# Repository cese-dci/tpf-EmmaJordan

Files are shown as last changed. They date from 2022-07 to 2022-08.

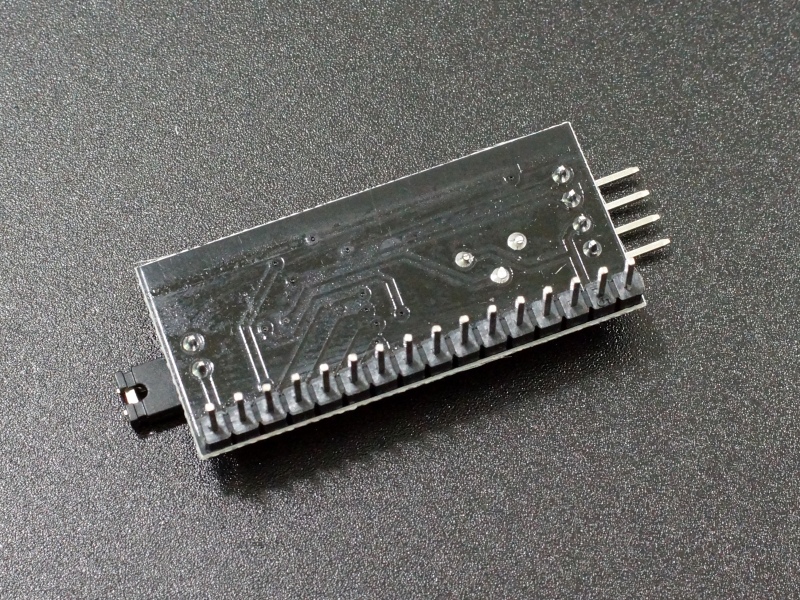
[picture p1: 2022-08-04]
doc/LCDi2c Vista Inferior.jpg

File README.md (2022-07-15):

## Trabajo práctico final de la asignatura DCI ##
Este repositorio contiene el trabajo práctico final para la asignatura de Diseño de Circuitos Impresos de la carrera de posgrado de FIUBA.

* Autor: Jordán Joan Emmanuel
* Título corto del trabajo:  Adaptador LCD i2c para Displays Alfanuméricos
* Resumen:  Este trabajo consiste en el diseño de una placa electrónica para control de Displays Alfanuméricos desde microcontrolador.
Mediante interfaz LCD-i2c. La placa utiliza como integrado principal el PCF8574, el cual traduce la comunicación i2c con el microcontrolador
a puerto paralelo para el Display, el cual puede ser 16x02, 20x4, 40x2, etc.

* Descripción: El módulo LCD-i2c es un expansor de puertos I2C, para controlar desde un microcontrolador con sólo dos pines (SCL y SDA), 
un display alfanumérico tipo 16x2, 20x4, 40x2, etc. Cuenta con un potenciómetro para ajustar el contraste de la pantalla y un jumper para 
habilitar su backlight. Cuenta con un selector de tres palancas para modificar la dirección de esclavo (pines A0, A1 y A2) lo que permite 
direccionar hasta 8 módulos iguales en el mismo bus de comunicación. La dirección predeterminada es 0x27, y puede ser detectada por el 
programa. El integrado principal de este módulo es el expansor i2c PCF8574.

## Licencia de este trabajo ##
CERN Open Hardware Licence 

## Estructura del TP FINAL ##

Se propone y se pide utilizar la siguiente estructura.

* doc: Toda la información sobre el circuito, principalmente de autoría o procesamiento propio. Por ejemplo:
  * Notas de ingeniería propias.
  * Notas de aplicación propias.
  * Estudios previos, estado del arte, resumen de las investigaciones.
  * Notas con cálculos.
  * Dibujos adicionales.
  * Fotos de los prototipos.
  * Presupuestos, cotizaciones.
* info: Toda la información recolectada, principalmente de terceros, como por ejemplo:
  * Hojas de datos.
  * Notas de aplicación.
  * Info de productos comerciales.
  * Info en internet.
* pcb: Archivos de diseño esquemático y pcb.

Dependiendo la magnitud del proyecto, tendremos más o menos información en estos directorios. 
Revisar los README.md en cada directorio para conocer las pautas de cada uno para este TP.

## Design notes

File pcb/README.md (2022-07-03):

## Archivos Kicad ##

En este directorio se incluye:

* Archivos de proyecto.
* Esquemático.
* PCB.
* Modelos 3D.
* Bibliotecas de símbolos y huellas externas (si son necesarios).

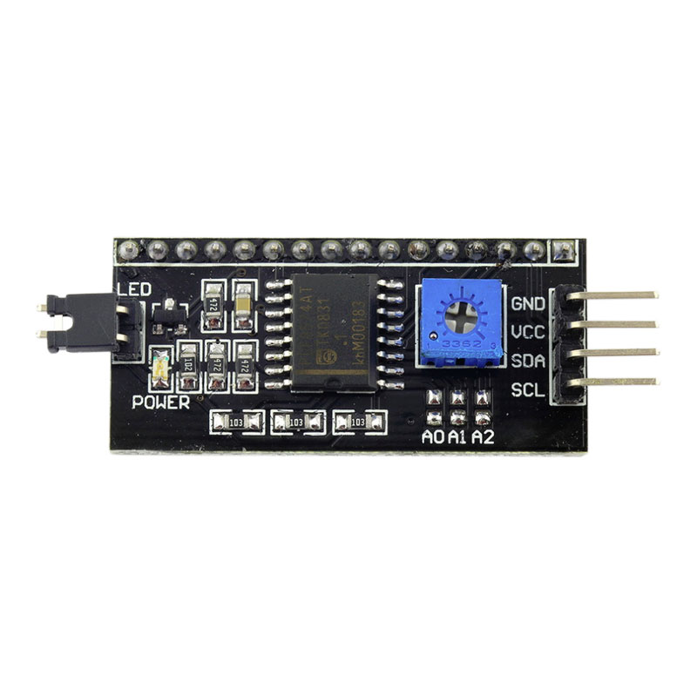
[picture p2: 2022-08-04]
doc/LCDi2c Vista Superior.jpg

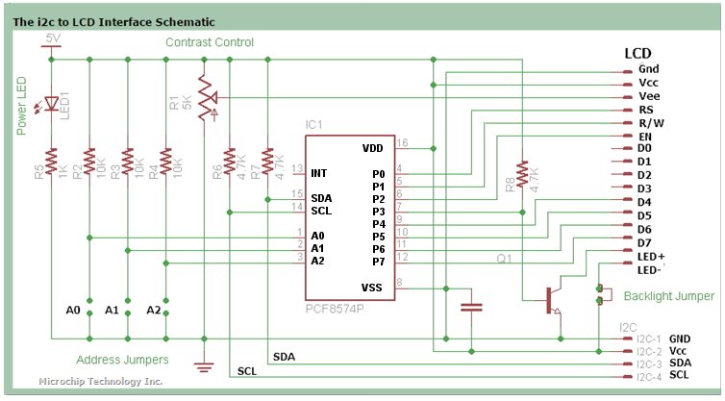
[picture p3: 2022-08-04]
doc/PCF8574_LCD_module.png

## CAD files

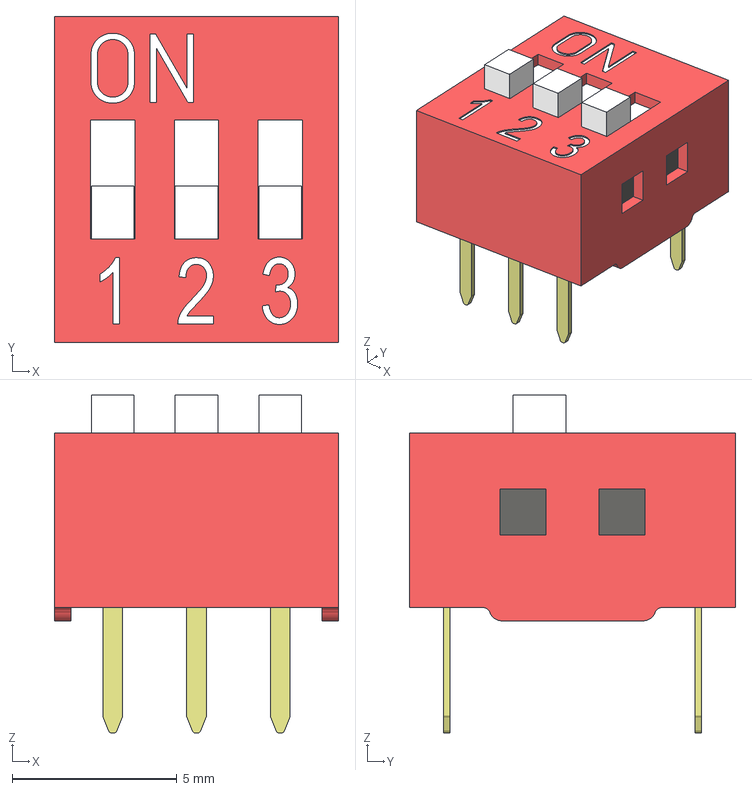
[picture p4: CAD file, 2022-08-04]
pcb/mis3DModels/DIPSwitch_03.stp
8.62 x 9.90 x 10.2 mm
DIP Switch Contact x 6
DIP Switch x03 Innenteil
DIP Switch Schalter x 3
DIP Switch x03_1

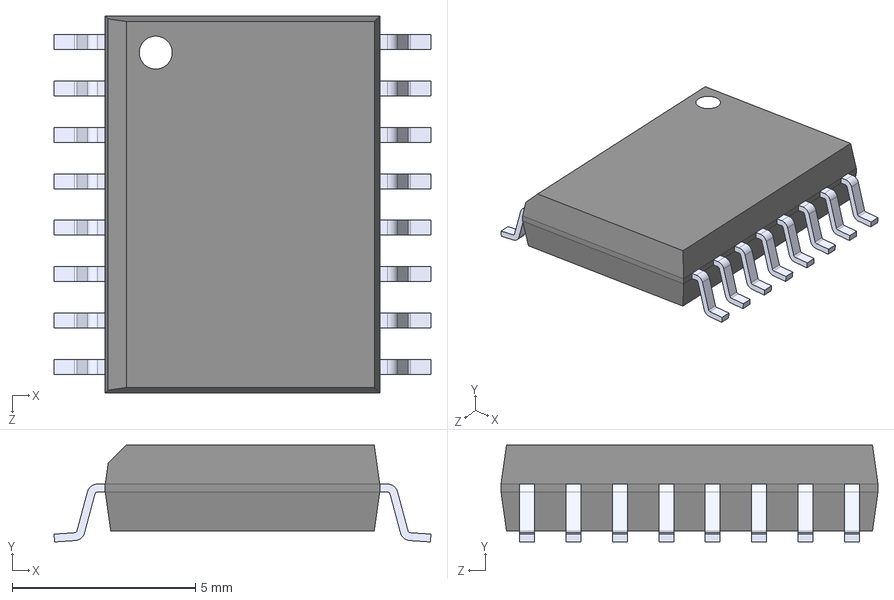
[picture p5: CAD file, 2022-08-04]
pcb/mis3DModels/PCF8574DW.step
10.3 x 2.65 x 10.3 mm

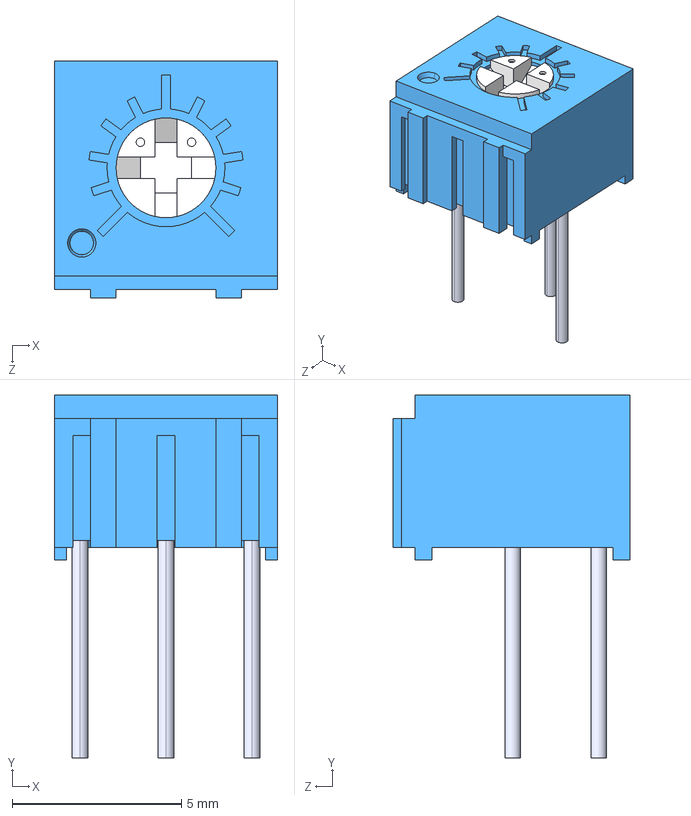
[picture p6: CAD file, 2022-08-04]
pcb/mis3DModels/miPoteHorizontal.STEP
6.60 x 10.7 x 6.99 mm

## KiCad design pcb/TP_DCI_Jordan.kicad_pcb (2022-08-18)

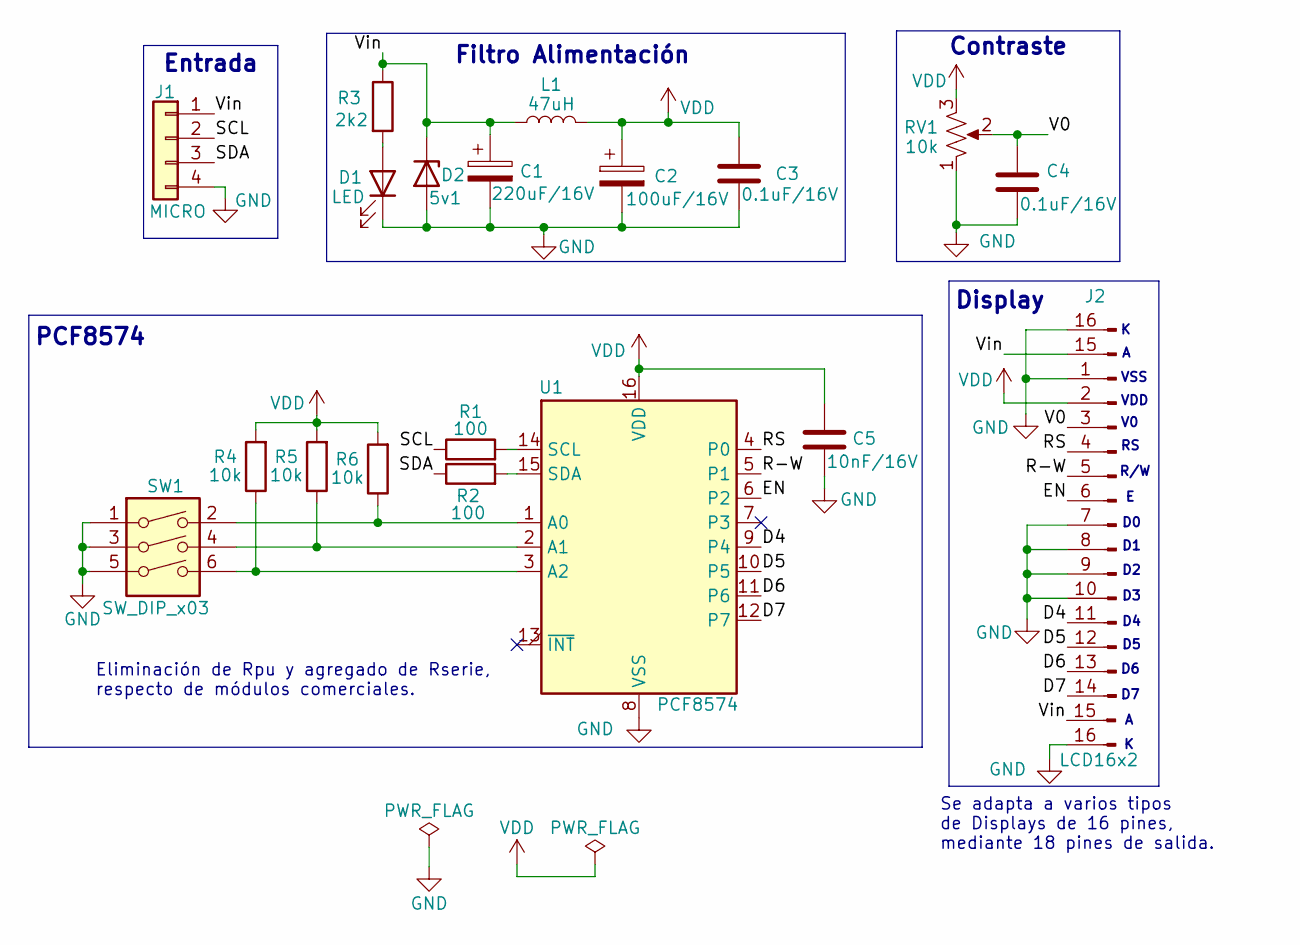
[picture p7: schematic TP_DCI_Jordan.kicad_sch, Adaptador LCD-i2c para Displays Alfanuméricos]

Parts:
C1: 220uF/16V; CP_Elec_5x3.9
C2: 100uF/16V; CP_Elec_5x3.9
C3, C4: 0.1uF/16V; C_0805_2012Metric
C5: 10nF/16V; C_0805_2012Metric
D1: LED; LED_0805_2012Metric_Pad1.15x1.40mm_HandSolder
D2: 5v1; D_0805_2012Metric_Pad1.15x1.40mm_HandSolder
J1: MICRO; PinHeader_1x04_P2.54mm_Vertical
J2: LCD16x2; LCD_16x2_dosTipos
L1: 47uH; L_0805_2012Metric_Pad1.15x1.40mm_HandSolder
R1, R2: 100; R_0805_2012Metric_Pad1.15x1.40mm_HandSolder
R3: 2k2; R_0805_2012Metric_Pad1.15x1.40mm_HandSolder
R4, R5, R6: 10k; R_0805_2012Metric_Pad1.15x1.40mm_HandSolder
RV1: 10k; miPote10k_3362P
SW1: SW_DIP_x03; DIPSwitch_03
U1: PCF8574; SOIC127P1030X265-16N

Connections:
/D4: J2.11, U1.9 (P4)
/D5: J2.12, U1.10 (P5)
/D6: J2.13, U1.11 (P6)
/D7: J2.14, U1.12 (P7)
/EN: J2.6, U1.6 (P2)
/R-W: J2.5, U1.5 (P1)
/RS: J2.4, U1.4 (P0)
/SCL: J1.2, R1.1
/SDA: J1.3, R2.1
/V0: C4.1, J2.3, RV1.2
/Vin: C1.1, D2.1 (K), J1.1, J2.15, L1.1, R3.1
GND: C1.2, C2.2, C3.2, C4.2, C5.2, D1.1 (K), D2.2 (A), J1.4, J2.1, J2.7, J2.8, J2.9, J2.10, J2.16, RV1.1, SW1.1, SW1.3, SW1.5, U1.8 (VSS)
unnamed: D1.2 (A), R3.2
unnamed: R1.2, U1.14 (SCL)
unnamed: R2.2, U1.15 (SDA)
unnamed: R5.1, SW1.4, U1.2 (A1)
unnamed: R6.1, SW1.2, U1.1 (A0)
unnamed: R4.1, SW1.6, U1.3 (A2)
VDD: C2.1, C3.1, C5.1, J2.2, L1.2, R4.2, R5.2, R6.2, RV1.3, U1.16 (VDD)

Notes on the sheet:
Filtro Alimentación
PCF8574
Display
Contraste
VSS
Entrada
Eliminación de Rpu y agregado de Rserie, respecto de módulos comerciales.
Se adapta a varios tipos de Displays de 16 pines, mediante 18 pines de salida.
VDD
R/W

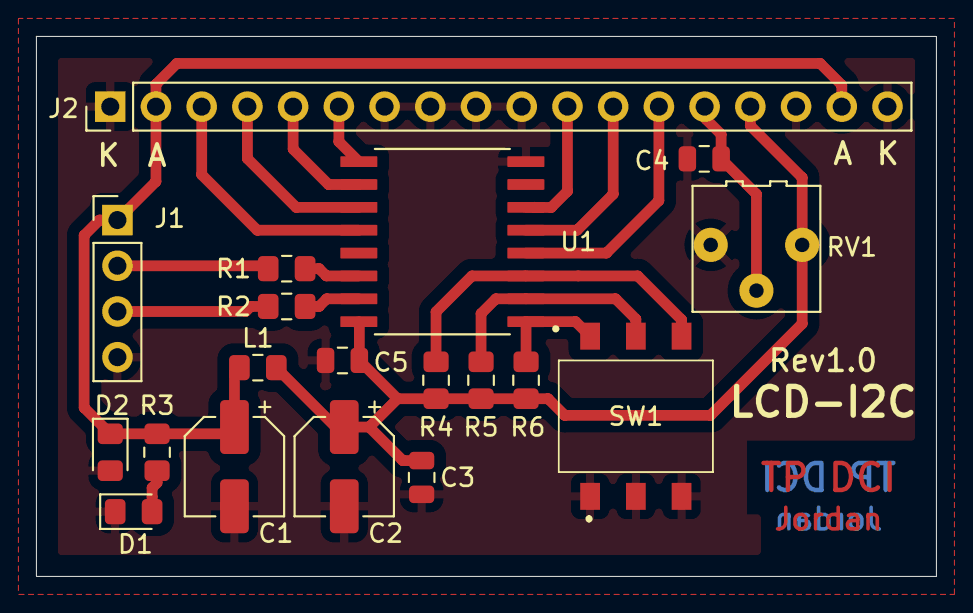
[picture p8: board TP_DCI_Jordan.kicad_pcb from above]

Board: 2 copper layers, 50.0 x 30.0 mm, 19 parts (0 on the bottom side), 19 nets.

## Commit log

2022-07-03 Se comienza esquemático de componentes en KiCAD
    [TP_DCI_Jordan.kicad_pcb, TP_DCI_Jordan.sch]
2022-07-03 Rótulo en esquemático
    [TP_DCI_Jordan.sch]
2022-07-15 avance con esquemático
    [TP_DCI_Jordan.kicad_pcb, TP_DCI_Jordan.sch]
2022-07-15 huella SMD para PCF8574 y DIPSwitch
    [TP_DCI_Jordan.kicad_pcb, TP_DCI_Jordan.sch]
2022-07-15 creación de PCB y orden de primeros elementos
    [TP_DCI_Jordan.kicad_pcb, TP_DCI_Jordan.sch]
2022-07-24 Se agrega borde y margen de PCB
    [TP_DCI_Jordan.kicad_pcb]
2022-07-28 mejora de esquemático
    [TP_DCI_Jordan.sch]
2022-07-28 actualización de PCB con primeras huellas SMD
    [TP_DCI_Jordan.kicad_pcb]
2022-07-29 asociación de huellas SMD recomendadas
    [TP_DCI_Jordan.sch]
2022-07-29 actualización PCB con elementos SMD correctos
    [TP_DCI_Jordan.kicad_pcb]
2022-08-04 se emprolija esquemático, buenas prácticas de flujo de señales
    [TP_DCI_Jordan.sch]
2022-08-04 agregado de PWR flags, cero errores ERC
    [TP_DCI_Jordan.sch]
2022-08-04 se acomoda serigrafía en PCB
    [TP_DCI_Jordan.kicad_pcb]
2022-08-04 carpetas doc e info ok
    [TP_DCI_Jordan.kicad_pcb]
2022-08-04 Clearance y DCR ok
    [TP_DCI_Jordan.kicad_pcb]
2022-08-04 más info en rótulos
    [TP_DCI_Jordan.kicad_pcb]
2022-08-04 revisión huella PCF8574 ok
    [TP_DCI_Jordan.sch]
2022-08-04 minimización tamaño PCB
    [TP_DCI_Jordan.kicad_pcb]
2022-08-04 mis 3D y libs
    [DIPSwitch_03.stp, PCF8574DW.step, miPoteHorizontal.STEP]
2022-08-04 Comentarios en bloques
    [TP_DCI_Jordan.sch]
2022-08-04 medición longitudes de PCB
    [TP_DCI_Jordan.kicad_pcb]
2022-08-04 configuración de vías
    [TP_DCI_Jordan.kicad_pcb]
2022-08-12 detalles en esquemático
    [TP_DCI_Jordan.sch]
2022-08-12 rellenos de GND no superpuestos
    [TP_DCI_Jordan.kicad_pcb]
2022-08-17 actualización de KiCAD6.0
    [TP_DCI_Jordan.kicad_pcb, TP_DCI_Jordan.kicad_sch, TP_DCI_Jordan.sch]
2022-08-18 maximizar espaciado entre conductores, IPC
    [TP_DCI_Jordan.kicad_pcb]
2022-08-18 presentación final
    [TP_DCI_Jordan.kicad_pcb, TP_DCI_Jordan.kicad_sch]

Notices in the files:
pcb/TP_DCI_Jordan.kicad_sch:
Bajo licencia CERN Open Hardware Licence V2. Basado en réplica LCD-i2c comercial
